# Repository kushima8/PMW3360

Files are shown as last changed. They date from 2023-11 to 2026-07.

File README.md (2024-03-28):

# **PMW3360**

## Open Json files with EasyEDA.
### ・SCH_PMW3360_Sensor Board.json
### ・PCB_PMW3360_Sensor Board.json

PMW3360 breakout board for trackball/mouse. Compatible with 1.8V - 5.5V Vcc.


## **BOM**
|Name |Value  |Footprint  |Qty |
|:---: |:---:  |:---: |:---:  |
|C1,C3,C6,C7,C9,C12,C13 |100nF  |0805 |7 |
|C2,C5 |1uF |0805 |2 |
|C4,C8,C11,C14 |10uF |0805 |4 |
|C10 |4.7uF  |0805 |1 |
|DMOSI,DNCS,DSCLK |3.3V |SOD-323 |3 |
|R1 |52.3k  |0805 |1 |
|R3 |37.4k  |0805 |1 |
|R4 |39 Ohm |0805 |1 |
|R5 |63.4k  |0805 |1 |
|R6,R7 |10k |0805 |2 |
|R8 |30.1k  |0805 |1 |
|U1,U3 | |SOT23 |2 |
|PMW3360 + lens | | |1 |

# Build Guide

[ビルドガイド（日本語）](documents/buildguide.md)  
[トラックボールケース](stl)

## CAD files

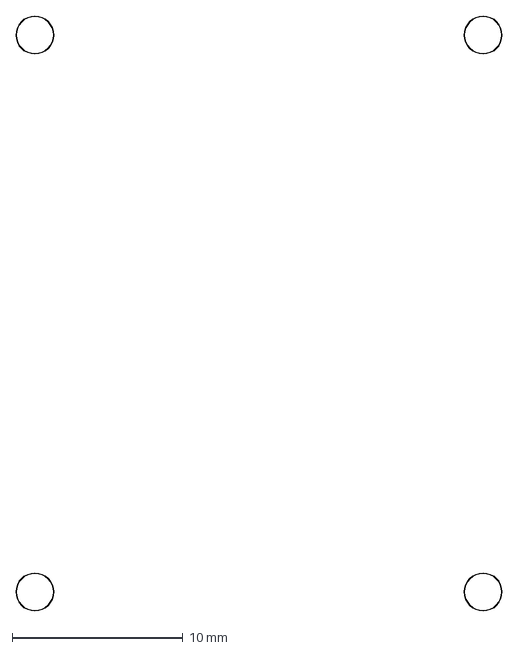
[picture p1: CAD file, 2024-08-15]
img/pmw3360_kushima8_format_M2_Hole.dxf
28.4 x 34.8 mm

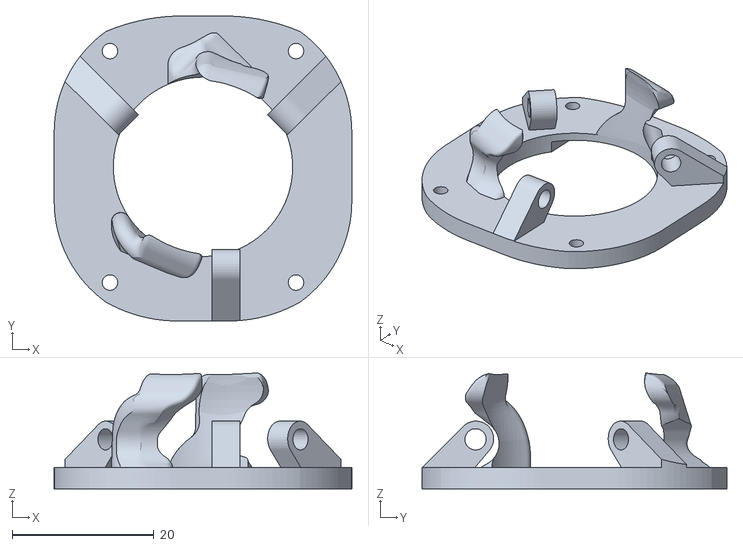
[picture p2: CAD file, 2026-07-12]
stl/reex_25mm_low_V2_L.stl
42.0 x 43.0 x 16.4

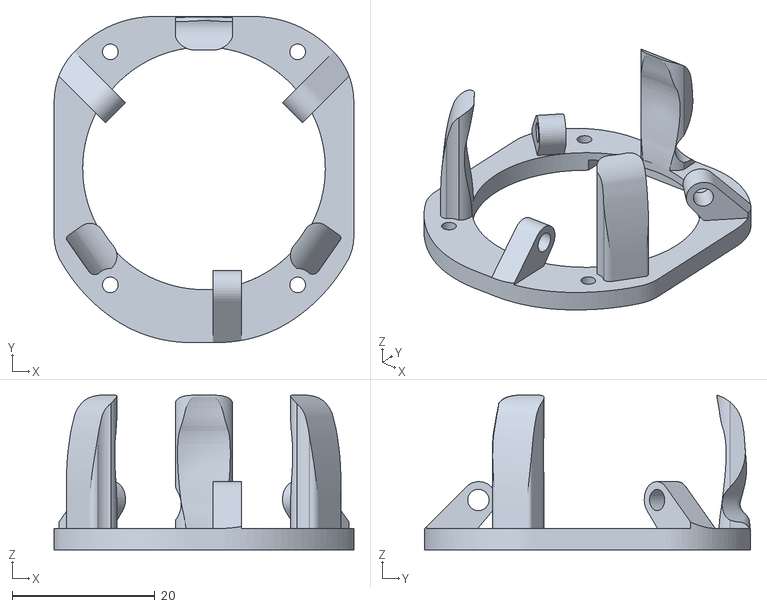
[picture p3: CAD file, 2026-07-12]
stl/reex_34mm_low_V2.stl
42.0 x 45.7 x 21.7

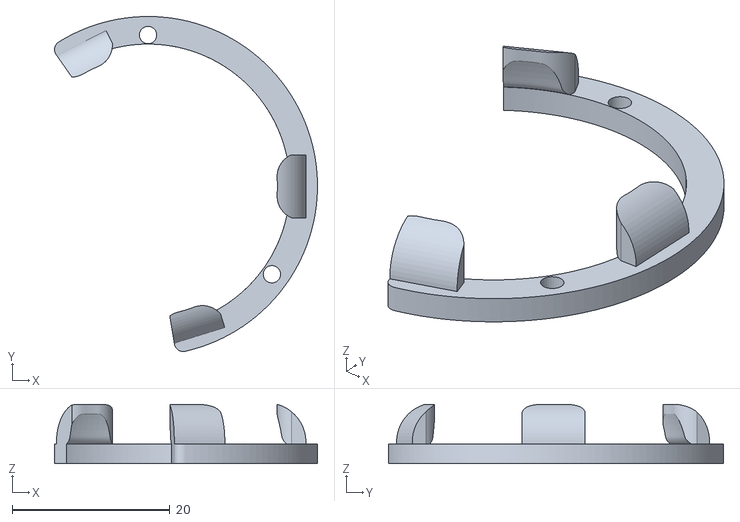
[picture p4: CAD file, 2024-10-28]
stl/reex_34mm_topcover_Lplam_V2.stl
33.4 x 42.5 x 7.55

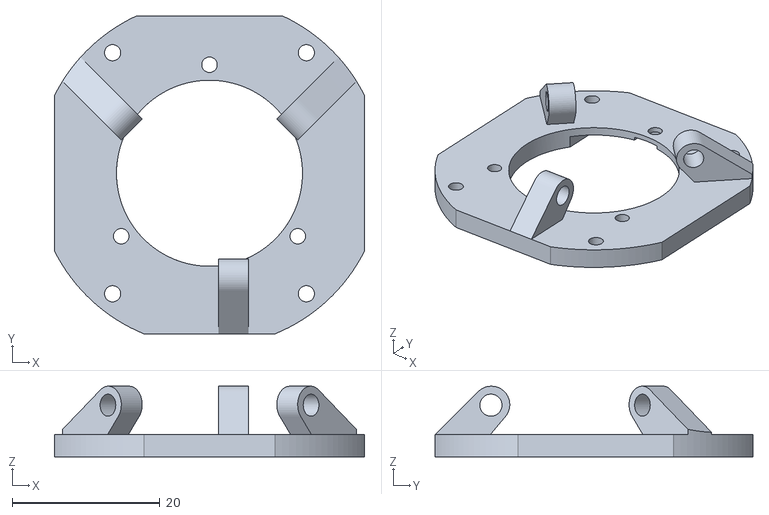
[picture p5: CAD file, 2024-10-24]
stl/reex_25mm_low.stl
42.0 x 43.0 x 9.58

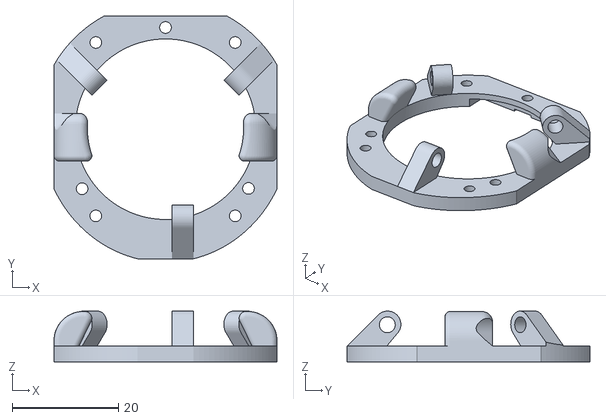
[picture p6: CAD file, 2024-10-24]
stl/reex_34mm_low_bulge.stl
42.0 x 45.7 x 9.57

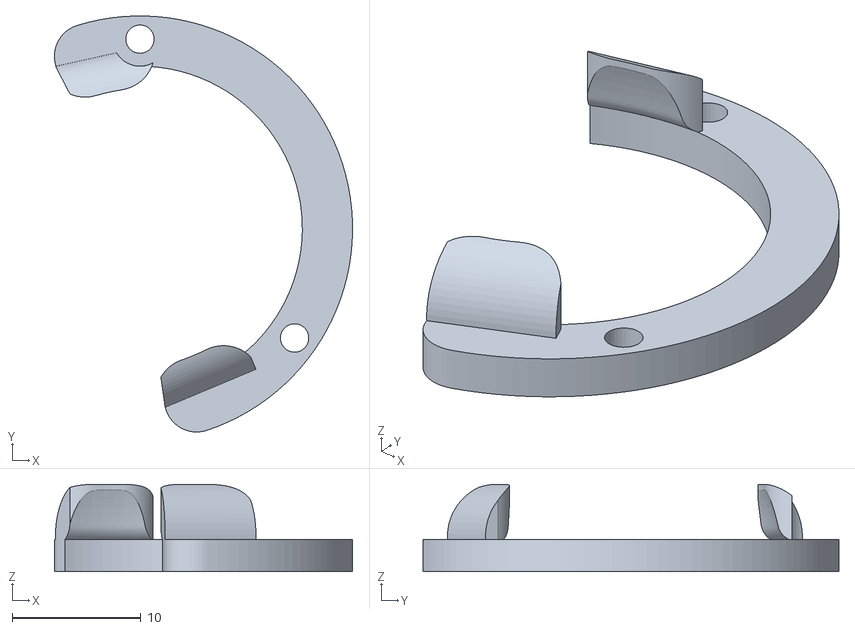
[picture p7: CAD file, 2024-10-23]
stl/reex_25mm_topcover_Lplam.stl
23.1 x 32.3 x 6.76

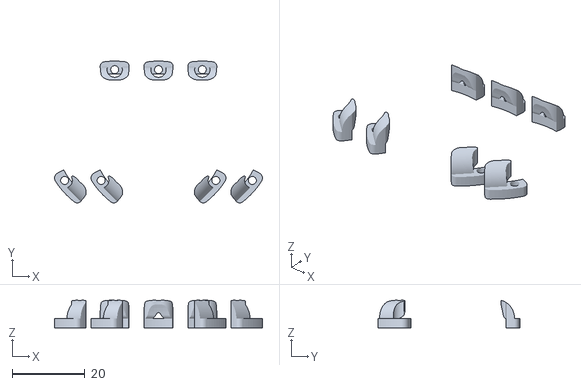
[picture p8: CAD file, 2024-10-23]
stl/reex_34mm_topcover_nail.stl
57.0 x 38.9 x 7.55

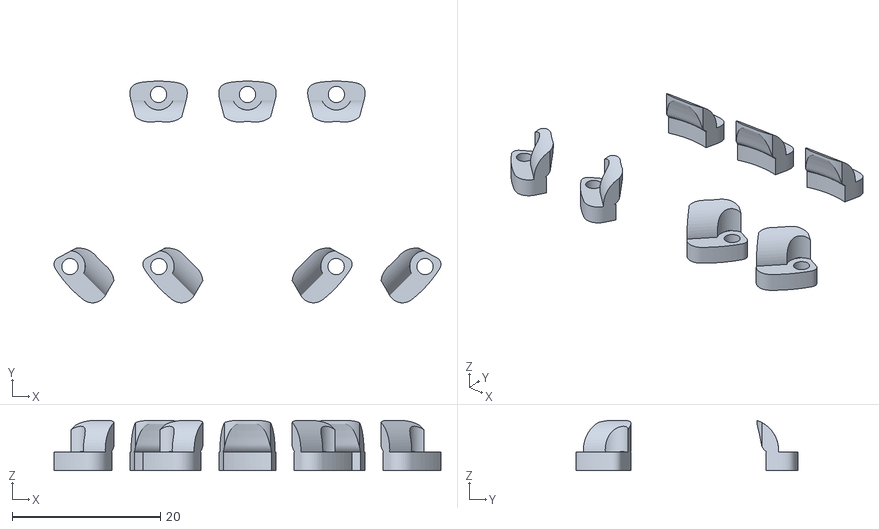
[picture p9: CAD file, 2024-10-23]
stl/reex_25mm_topcover_nail.stl
52.2 x 29.9 x 6.76

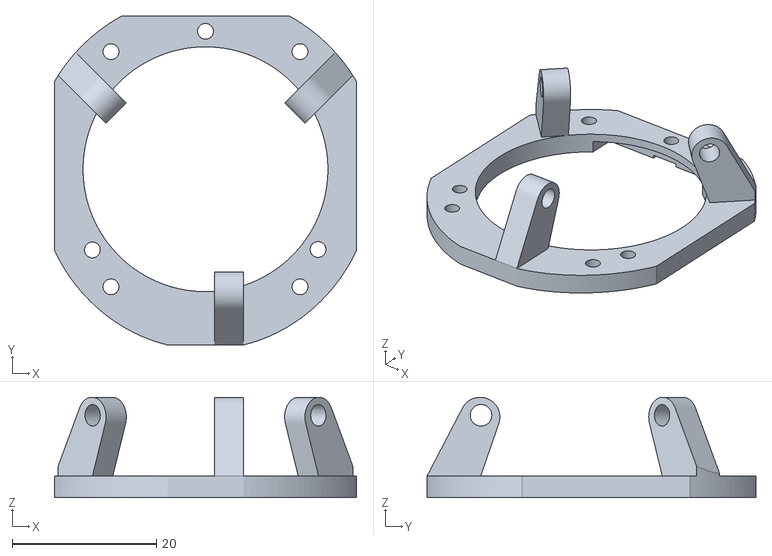
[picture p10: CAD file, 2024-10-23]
stl/reex_34mm_high.stl
42.0 x 45.7 x 14.0

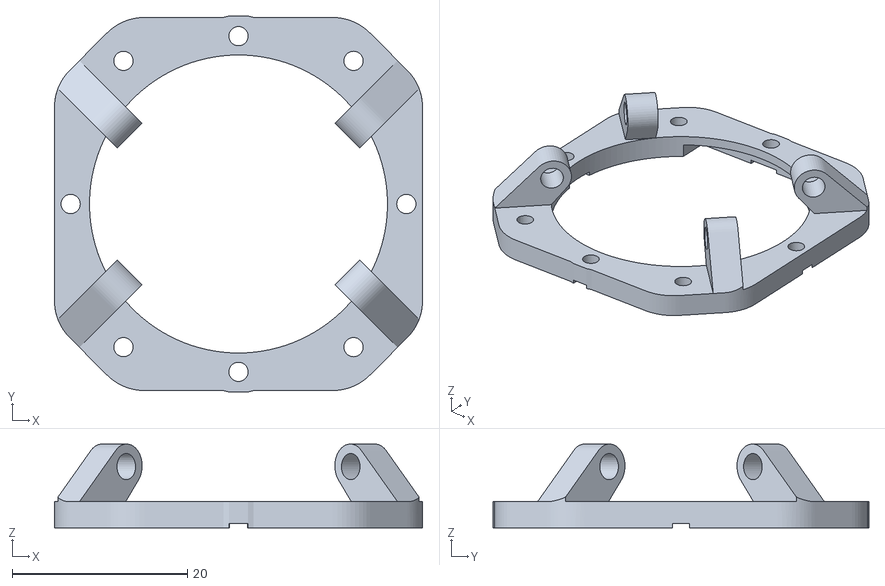
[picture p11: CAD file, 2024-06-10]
stl/reex_34mm_low_4pillar.stl
42.0 x 42.9 x 9.57

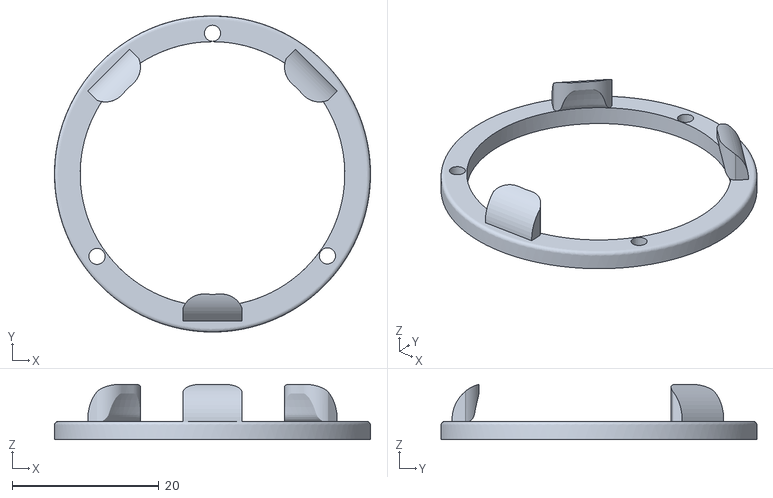
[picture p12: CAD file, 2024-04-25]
stl/reex_34mm_topcover_ring.stl
43.0 x 43.0 x 7.55

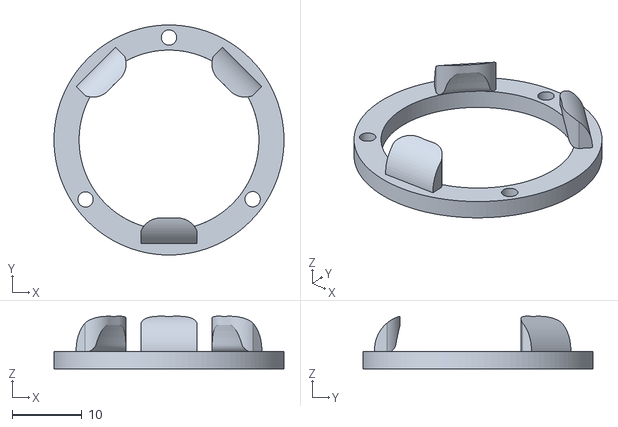
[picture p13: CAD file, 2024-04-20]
stl/reex_25mm_topcover_ring.stl
33.0 x 33.0 x 7.55

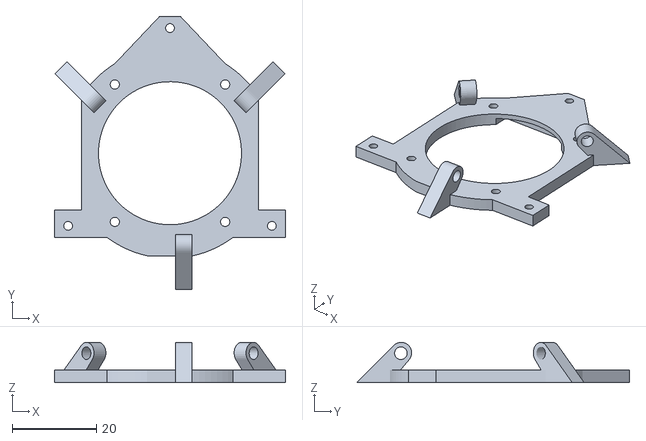
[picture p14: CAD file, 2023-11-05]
stl/reex_55mm_low.stl
55.0 x 64.9 x 9.58

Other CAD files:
stl/reex_25mm_low_V2_R.stl
stl/reex_34mm_topcover_Rplam_V2.stl
stl/reex_25mm_topcover_Rplam.stl
stl/reex_34mm_low.stl
stl/old_reex_34mm_topcover_Lplam.stl
stl/old_reex_34mm_topcover_Rplam.stl
stl/reex_34mm_topcover_Lplam.stl
stl/reex_34mm_topcover_Rplam.stl

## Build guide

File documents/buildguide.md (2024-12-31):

# PMW3360ブレイクアウトボードビルドガイド

### 付属しているもの

|名称|数量|備考|
|----|:---:|----|
|PMW3360ブレイクアウトーボード|1個||
|PMW3360DM-T2QU|1個|レンズ付き|
|ステンレスミニアチュアベアリング(3×6×2.5mm)|3個||
|六角ナット(M3 厚さ2.4mm)|3個||
|(+)ナベ頭小ねじ(M3 10mm)|3個||
|34mm版トラックボールケース|1個|ローマウント版|
|34mm版トラックボールケースカバー(爪)|3個||
|34mm版トラックボールケースカバー(右リング)|1個||
|34mm版トラックボールケースカバー(左リング)|1個||
|M2 2.5mmスペーサー(ARB-2002.5E)|4個|丸型中空|
|M2 3.5mmスペーサー(ARB-2003.5E)|4個|丸型両メネジ|
|M2 4mmスペーサー(ARB-2004E)|5個|丸型両メネジ|
|M2 10mmスペーサー(ARB-2010E)|3個|丸型両メネジ|
|M2 4mmネジ|7本|
|M2 10mmネジ|7本|
  
左：ローマウント  右：ハイマウント  


※以下のPro Microでのみ動作確認済み  
　https://shop.yushakobo.jp/products/pro-micro?variant=42225070768359

## PMW3360はんだ付け 



左から  ブレイクアウトボード、PMW3360、レンズ  



ブレイクアウトボードの既にダイオードやICがはんだ付けされている⾯を表にし、4つのスルーホールが2列になっている方を左側してください。  
センサチップの⽂字が書かれている⽅を下にしてブレイクアウトボードにセットしたあと、裏面からはんだ付けをしてください。  
はんだ付けが終わったらセンサに貼られているシールを剥がしてください。<br>

## ケースの作成

ケースは突起のある方が表側、その突起が2つある⽅が上、突起が1つの方が下となります。  
初めに上側のネジ⽳にM2 ネジを⼀つづ⼊れます。  
このM2ネジは使用用途にあわせてご自身でご用意ください。<br>

その後ベアリングを入れたM3 10mmネジを突起の穴に入れます。  
入れる方向などは下記画像を参考にしてください。  
設置後、六角ナットで固定してください。  
固定する際突起部分とベアリング部分を完全に密着せず若干ながら隙間を作るようにしてください。  
密着しすぎるとベアリングがうまく回らない場合があります。<br>

ケースを裏返して、M2 10mmネジを画像の三箇所に挿入してください。  
挿入後、M2 4mmスペーサー、M2 10mmスペーサーの順でネジに取り付けます。  
その後、スペーサーの上にトラックボールケースカバー(爪or右リングor左リング)を配置しM2 4mmネジで固定。  
このとき取り付けるトラックボールケースカバー(爪or右リングor左リング)はお好みに合わせて選択してください。<br>


一旦この状態でトラックボールを置き、干渉の確認をしてください。  
ケース本体は3Dプリンタで製造しており、玉と支柱のクリアリングは非常にタイトな設計な為、個体差によっては玉と支柱が干渉する場合があります。  
干渉する場合、支柱取り付けようのネジ穴を棒ヤスリなどで外側へ拡張し、干渉しない用に加工してください。  
下部にトラックボールユニットを取り付ける場合は親指が触れる位置の支柱を取り除くことをオススメします。

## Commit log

2022-01-13 Rename 1-PCB_PCB_PMW3360 Sensor Board.json to 1-PCB_PMW3360 Sensor Board.json
2023-03-06 Create Prototype
2023-03-06 Add STL
    [reex_bal_high.stl, reex_ball_low.stl]
2023-11-08 Update stl
    [reex_34mm_high.stl, reex_34mm_low.stl, reex_34mm_topcover..stl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]
2024-04-14 update & add stl
    [reex_25mm_topcover.stl, reex_34mm_high.stl, reex_34mm_low.stl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]
2024-04-17 del stl
    [reex_25mm_topcover_nail.stl, reex_34mm_topcover_nail.stl]
2024-08-15 footprints and dxf file added
    [pmw3360_kushima8_format_M2_Hole.dxf]
